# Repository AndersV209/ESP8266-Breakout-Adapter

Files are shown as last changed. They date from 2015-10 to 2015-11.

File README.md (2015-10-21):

###ESP-07 & ESP-12 Breakout Adapter

####Version 1.0 - LM1117 - AndersV209 custom (untested)
Used LDO: AMS1117
Vin=4.8-15V, Dropout=1.2V, Iq=5mA(-10mA)

####Version 1.1 - LM1117 (tested, works great)
Used LDO: LM1117
Vin=4.8-15V, Dropout=1.2V, Iq=5mA(-10mA)

oshpark: https://oshpark.com/shared_projects/9CsYq2PY

####Version 2.0A - AS1363 (untested, in production)
Used LDO: AS1363
Vin=3.5-5.5V, Dropout=150mV(-320mV), Iq=40µA

oshpark: https://oshpark.com/shared_projects/2IkxaFPm

####Version 2.0B - SPX3819 (untested, in production)
Used LDO: SPX3819 
Vin=3.7-16V, Dropout=340mV(-550mV), Iq=90µA

oshpark: https://oshpark.com/shared_projects/jsl8ZcFp

####Version 3.0A - AS1363 - Mini (untested)
Used LDO: AS1363
Vin=3.5-5.5V, Dropout=150mV(-320mV), Iq=40µA

oshpark: https://oshpark.com/shared_projects/BgaX81QE

####Version 3.0B - SPX3819 - Mini (untested)
Used LDO: SPX3819 
Vin=3.7-16V, Dropout=340mV(-550mV), Iq=90µA

oshpark: https://oshpark.com/shared_projects/zpDg7761

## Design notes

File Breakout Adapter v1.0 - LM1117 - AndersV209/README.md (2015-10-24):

CUSTOM Version by AndersV209

#ESP-12E Breakout Adapter

###Features
* 3V3 voltageregulator (LM1117/AMS1117/..)
* Breadboard compatible
* Reset Button
* Pullup restor for CH_PD

###Partlist:
**ESP8266**
* 1x - ESP12E/ESP12F

**Vreg**
* 1x - x1117-3.3 - [SOT223]

**Caps**
* 1x - 100nF - [0805]
* 2x - 10µF - [0805]

**Switches**
* 1x - Tactile Switch - [THT/SMD]

**Resistors**
* 3x - 10K - [0805]
* 1x - 0R - [0805]

**Pin Header**
* 2x - 1x13 - 2,54 mm 
* 1x - 1x6 - 2 mm 
* 2x - 1x8 - 2 mm 

###Resourcen:
* AMS1117 Datasheet - http://www.advanced-monolithic.com/pdf/ds1117.pdf
* LM1117 Datasheet - http://www.ti.com/lit/ds/symlink/lm1117-n.pdf

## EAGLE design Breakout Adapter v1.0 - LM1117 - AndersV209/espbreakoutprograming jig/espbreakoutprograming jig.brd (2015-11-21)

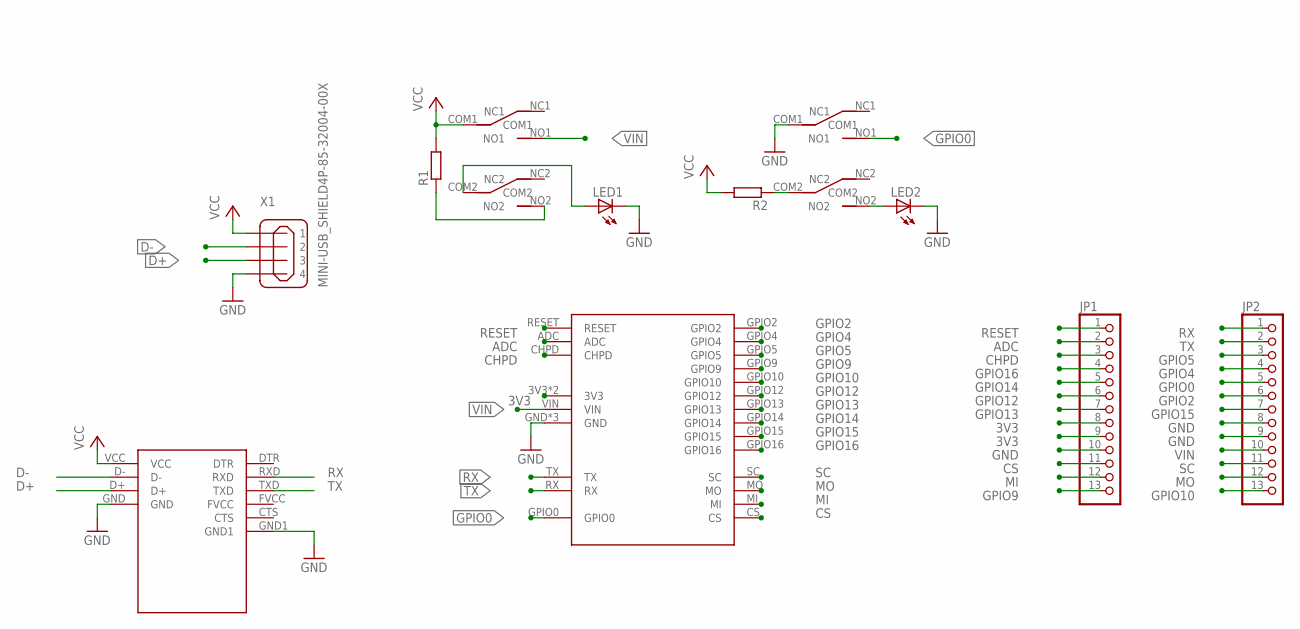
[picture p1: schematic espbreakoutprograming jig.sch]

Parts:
FLASH: TOGGLE_SWITCH; 7MMX7MM
JP1, JP2: PINHD-1X13; 1X13
LED1, LED2: LED5MM
POWER: TOGGLE_SWITCH; 7MMX7MM
R1, R2: R-EU_0207/10; 0207/10
U$1: USB-TTL; USB_TTL
U$2: ESP12EBREAKOUT
X1: MINI-USB_SHIELD4P-85-32004-00X; 85-32004-00X

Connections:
3V3: JP1.8, JP1.9, U$2.3V3, U$2.3V3_2 (3V3)
ADC: JP1.2, U$2.ADC
CHPD: JP1.3, U$2.CHPD
CS: JP1.11, U$2.CS
D+: U$1.D+, X1.3
D-: U$1.D-, X1.2
GND: FLASH.COM1, JP1.10, JP2.8, JP2.9, LED1.K (C), LED2.K (C), U$1.GND, U$1.GND1, U$2.GND, U$2.GND_2 (GND), U$2.GND_3 (GND), X1.4
GPIO0: FLASH.NO1, JP2.5, U$2.GPIO0
GPIO2: JP2.6, U$2.GPIO2
GPIO4: JP2.4, U$2.GPIO4
GPIO5: JP2.3, U$2.GPIO5
GPIO9: JP1.13, U$2.GPIO9
GPIO10: JP2.13, U$2.GPIO10
GPIO12: JP1.6, U$2.GPIO12
GPIO13: JP1.7, U$2.GPIO13
GPIO14: JP1.5, U$2.GPIO14
GPIO15: JP2.7, U$2.GPIO15
GPIO16: JP1.4, U$2.GPIO16
MI: JP1.12, U$2.MI
MO: JP2.12, U$2.MO
unnamed: POWER.NO2, R1.1
unnamed: LED1.A, POWER.COM2
unnamed: FLASH.COM2, R2.1
unnamed: FLASH.NO2, LED2.A
RESET: JP1.1, U$2.RESET
RX: JP2.1, U$1.RXD, U$2.TX
SC: JP2.11, U$2.SC
TX: JP2.2, U$1.TXD, U$2.RX
VCC: POWER.COM1, R1.2, R2.2, U$1.VCC, X1.1
VIN: JP2.10, POWER.NO1, U$2.VIN

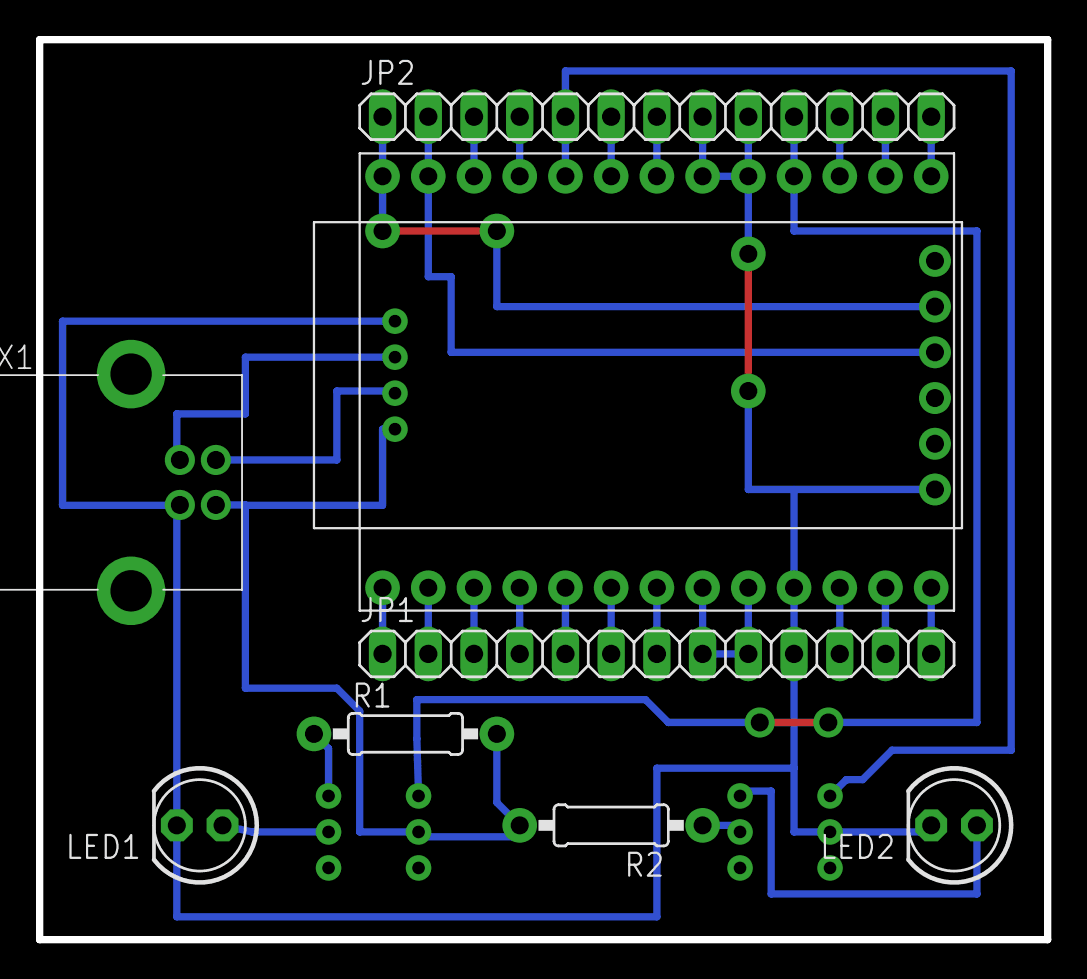
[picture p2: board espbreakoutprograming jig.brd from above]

Board: 2 copper layers, 56.0 x 50.0 mm, 11 parts (0 on the bottom side), 30 nets.

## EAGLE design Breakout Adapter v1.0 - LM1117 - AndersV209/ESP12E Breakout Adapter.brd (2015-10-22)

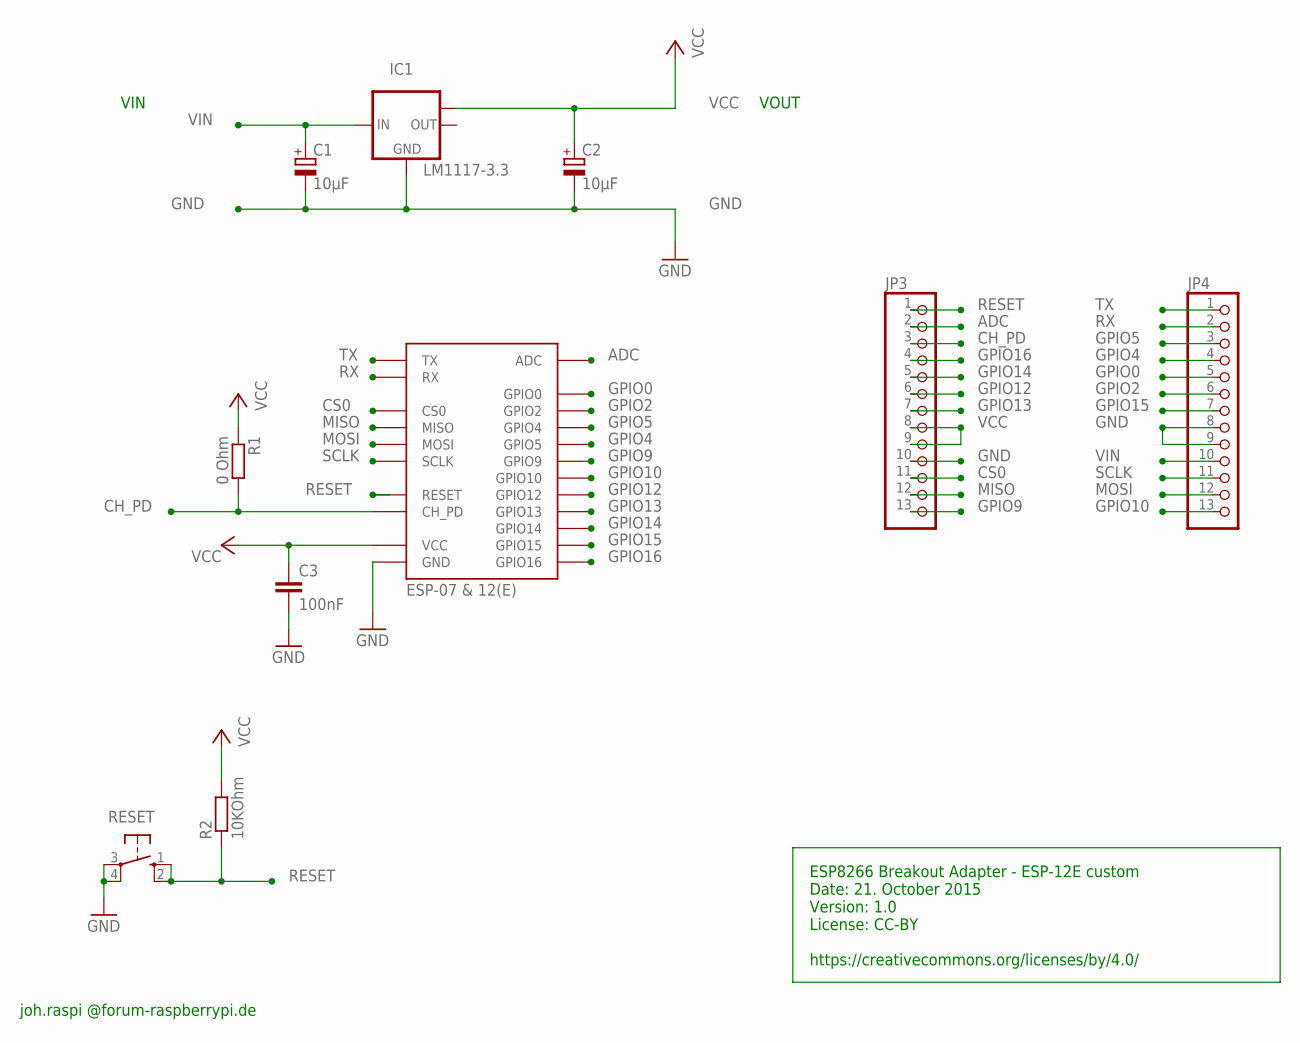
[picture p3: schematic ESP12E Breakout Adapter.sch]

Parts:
C1, C2: 10µF; B/3528-21W
C3: 100nF; C0805K
ESP8266: ESP-07 & 12(E); ESP-12-E
IC1: LM1117-3.3; SOT223
JP3, JP4: PINHD-1X13; 1X13
R1: 0 Ohm; R0805
R2: 10KOhm; R0805
RESET_SWITCH: RESET; B3F-10XX

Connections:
ADC: ESP8266.ADC, JP3.2
CH_PD: ESP8266.CH_PD, JP3.3, R1.2
CS0: ESP8266.CS0, JP3.11
GND: C1.-, C2.-, C3.2, ESP8266.GND, IC1.1 (GND), JP3.10, JP4.8, JP4.9, RESET_SWITCH.3, RESET_SWITCH.4 (P1); also elsewhere on the board
GPIO0: ESP8266.GPIO0, JP4.5
GPIO2: ESP8266.GPIO2, JP4.6
GPIO4: ESP8266.GPIO5, JP4.4
GPIO5: ESP8266.GPIO4, JP4.3
GPIO9: ESP8266.GPIO9, JP3.13
GPIO10: ESP8266.GPIO10, JP4.13
GPIO12: ESP8266.GPIO12, JP3.6
GPIO13: ESP8266.GPIO13, JP3.7
GPIO14: ESP8266.GPIO14, JP3.5
GPIO15: ESP8266.GPIO15, JP4.7; also elsewhere on the board
GPIO16: ESP8266.GPIO16, JP3.4
MISO: ESP8266.MISO, JP3.12
MOSI: ESP8266.MOSI, JP4.12
RESET: ESP8266.RESET, JP3.1, R2.1, RESET_SWITCH.1 (S), RESET_SWITCH.2 (S1)
RX: ESP8266.RX, JP4.2
SCLK: ESP8266.SCLK, JP4.11
TX: ESP8266.TX, JP4.1
VCC: C2.+, C3.1, ESP8266.VCC, IC1.TAB (OUT1), JP3.8, JP3.9, R1.1, R2.2
VIN: C1.+, IC1.3 (IN), JP4.10

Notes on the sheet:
VIN
VOUT
ESP8266 Breakout Adapter - ESP-12E custom Date: 21. October 2015 Version: 1.0 License: CC-BY https://creativecommons.org/licenses/by/4.0/
joh.raspi @forum-raspberrypi.de

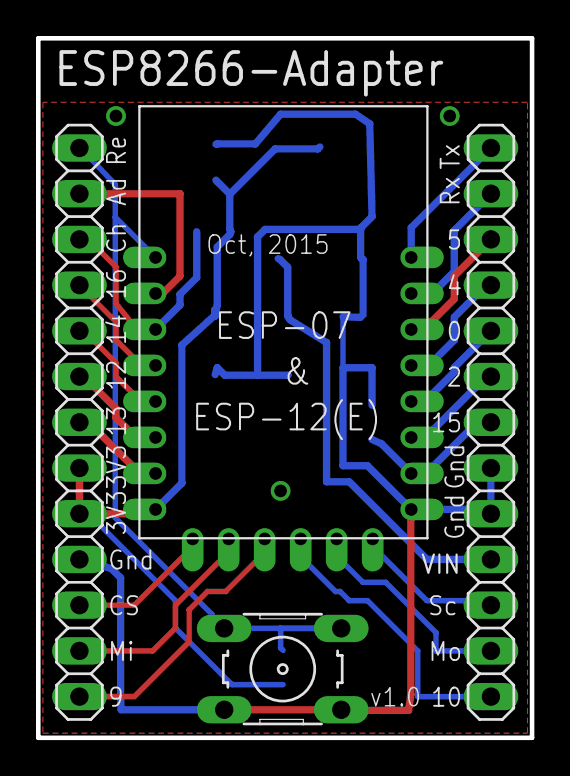
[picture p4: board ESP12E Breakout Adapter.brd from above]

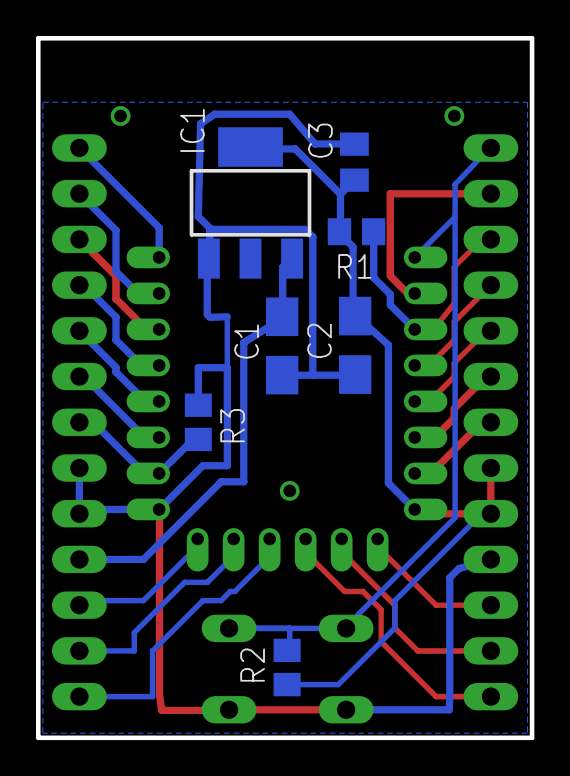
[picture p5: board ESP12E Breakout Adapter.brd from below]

Board: 2 copper layers, 27.5 x 38.8 mm, 11 parts (7 on the bottom side), 23 nets.

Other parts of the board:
R3: 10KOhm; R0805

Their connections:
GND: R3.1; also elsewhere on the board
GPIO15: R3.2; also elsewhere on the board

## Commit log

2015-10-21 Custum version of the ams1117 version
    My version of a ESP8266 esp12e breakout board(UNTESTED)
    [ESP12E Breakout Adapter.brd, ESP12E Breakout Adapter.sch]
2015-10-21 repostiton of esp12e
    [ESP12E Breakout Adapter.brd, ESP12E Breakout Adapter.sch]
2015-10-21 readme updated
    [ESP12E Breakout Adapter.brd]
2015-10-21 gerberfiles and clean up
    [ESP12E Breakout Adapter.brd, ESP12E Breakout Adapter.sch]
2015-10-22 update to silkscreen
    [ESP12E Breakout Adapter.brd]
2015-10-22 Gerberfile update to latest board
    [ESP12E Breakout Adapter.brd]
2015-10-22 clean up
    [ESP12E Breakout Adapter.brd]
2015-10-23 gerberfiles for dirtypcb
2015-10-23 esp moved and right capacitor footprint chosen
    [ESP12E Breakout Adapter.sch]
2015-10-23 final design for first pcb order
2015-10-24 esp12e breakout programing jig eagle files
    [espbreakoutprograming jig.brd, espbreakoutprograming jig.sch]
2015-11-21 update to programming jig
    [espbreakoutprograming jig.brd, espbreakoutprograming jig.sch]
2015-12-06 change to text on pcb as it was in wrong layer
